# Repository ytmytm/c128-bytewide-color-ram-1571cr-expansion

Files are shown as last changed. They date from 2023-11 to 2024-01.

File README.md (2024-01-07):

# C128 8-bit Color RAM and C128DCR 1571CR RAM expansion

This is a 24 to 28 pin adapter PCB that can be used for three different C128 modifications:

- widen 2K Color RAM to 8 bits (C128/C128D/C128DCR)
- widen Color RAM to 8 bits and expand to 32K (C128/C128D/C128DCR)
- RAM Expansion for 1571CR compatible with Maverick (C128DCR only)

## Schematic

PDF plot of [the schematic can be found here](kicad/plots/kicad-c128-byte-wide-color-ram.pdf).

[kicad](kicad/) folder contains all the KiCad 6.0 project files.

## PCB

[kicad/plots](kicad/plots) folder contains Gerber files for manufacturing a PCB for any of these projects.

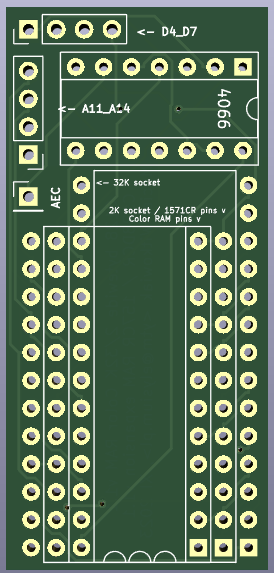
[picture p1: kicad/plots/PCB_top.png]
Top side of the PCB
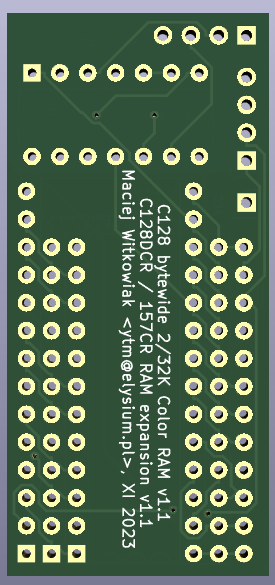
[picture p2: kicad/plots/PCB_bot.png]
Bottom side of the PCB


# 8-bit Color RAM

## Background

The idea comes from [a project published in 1990](http://www.sdiy.org/richardc64/color/byte.html).

All C128 variations use 8x2K SRAM chip (2016) for Color RAM. Although RAM is 8-bit, only lower 4 bits are connected. Lines D4-D7 are pulled up by a resistor pack to 5V.
This project replicates part of the onboard circuit and adds a quad switch 4066 as a bidirectional buffer between higher 4 bits and CPU bus.
Like the onboard U20 (4066) it switches Color RAM on/off bus, depending on the state of AEC line.

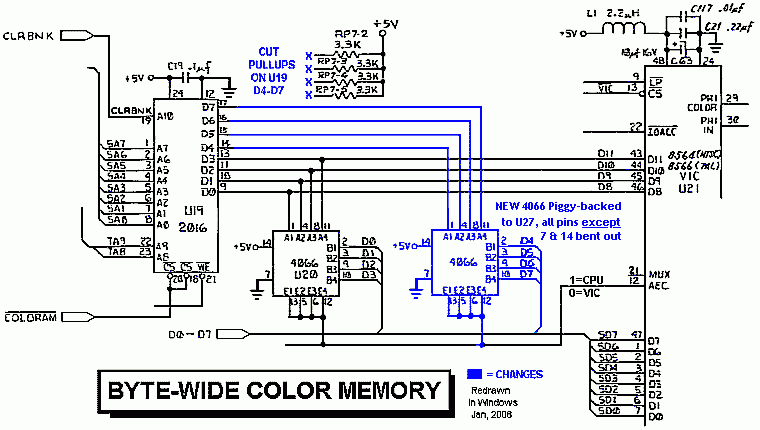
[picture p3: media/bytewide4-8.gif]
Schematic from http://www.sdiy.org/richardc64/color/byte.html


Note: this schematic shows the general idea. Don't cut anything on the mainboard and don't piggyback chips

## Why?

For sure it doesn't add any colors. However having 1K (2K in C128 mode) of additional RAM may be useful for some projects. It is compatible with any other expansion or cartidge.

## 32K option

Even more of that RAM? Possibilities are endless, but how to switch the banks?

VIC utilizes 1K of Color RAM, but C128 was equipped with double of that amount to support split screen multicolor graphics in BASIC. The bank switching between lower 1K and upper 1K is done using CPU port at location $01.
In C64 mode this port decides about RAM/ROM configuration, in C128 mode lower two bits determine which half of 2K Color RAM is seen by VIC and which half by CPU.

It only made sense to me to extend this further and use other $01 port bits to provide more address lines for 32K Color RAM expansion. None of my C128s will be ever used with tape (or even TapeCart), so I connected A11-13 lines to
lines normally used by tape motor control, tape write and sense bits. This provides 13 bits of address, so 16K total.

You don't need to connect all of them or you can skip it altogether. I have reused connections to onboard pull-up resistors to pull these address lines high if nothing is connecte to the solder pads.

Until I have a better idea where to connect A14 I will be happy with using 16K of that RAM. That's enough for 16 full screens: 8 for imaginary FLI mode with color ram switched every line and another 8 for interlaced option.

Note that a lot of C64 software will write to CPU port ($01) location and can modify the status of tape control bits. If you're not planning to use tape device I highly recommend patching the ROM (details below)
to set these bits as input by default. This completely removes the problem as virtually no software modifies CPU port direction register ($00).

## Assembly

Parts needed:

- 24-pin socket to be soldered in place of removed U19
- two sets of 12 round pins (24 total)
- 4066 analog quad switch and 14-pin socket for it
- 24-pin socket for 2K SRAM (2016) *or* 28-pin socket for 32K SRAM (62256)
- 8x2K RAM (ideally 2016 desoldered from the board) *or* 8x32K SRAM (62256)

In any case you need to remove or desolder the original 2K chip (U19) and replace it by a 24-pin socket. PCB is meant to be equipped with round pins and plugged into that socket.
We also need some signals from the board, so additional wires will be needed.

Start assembly by soldering in two rows of 24 round pins that will be used to plug in PCB to the C128/D/DCR mainboard.
For this project you need to solder them in the row of holes closest to the PCB edge and the one marked on silkscreen, on the image below marked by RED.

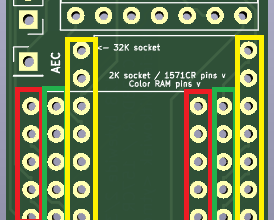
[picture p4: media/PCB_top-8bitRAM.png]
colour-coded pins


For 2K option solder the 24-pin socket in holes marked GREEN. For 32K option solder 28-pin socket in holes marked YELLOW.

The last step of the assembly is soldering in 14-pin socket for 4066.

## Installation

Once the assembled PCB is plugged into place of original SRAM (U19) (*mind the orientation*) you need to connect five additional wires to the mainboard:

- connect AEC from onboard U20 (4066) any pin 5, 6, 12 or 13 - they are all connected together
- connect D4-D7 in any order from charset ROM nearby or from convenient vias. You may have 24 or 28-pin ROM there, so check the pinout and verify against e.g. CPU

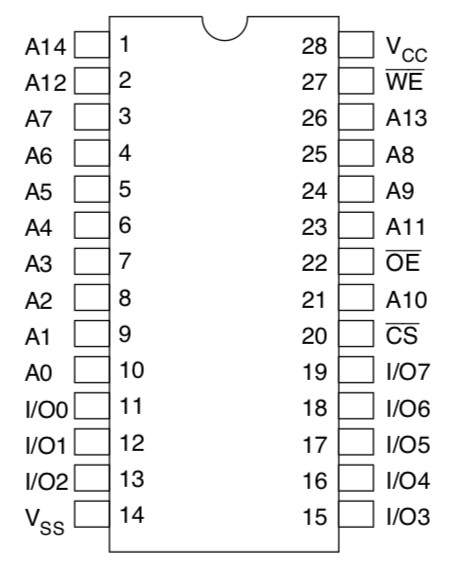
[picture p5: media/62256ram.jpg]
62256 SRAM pinout


D4-D7 lines are on the right bottom end of the chip.

**Note:** if you don't have 2K SRAM chip or it was damaged during desoldering you can just pop in 32K SRAM chip (still available these days) and stop here.
If you look on the schematics I have routed onboard D4-D7 lines (pulled high by onboard resistors) to A11-A14 lines.
So if you don't connect there anything at all they will be driven high and even with 32K SRAM those 2K of Color RAM will be available with no extra connections.

## Installation (32K Color RAM)

- connect A11/A12/A13 to CPU tape ports P3/P4/P5 from CPU socket (pins 27/26/25) or from convenient vias

Like with data lines it doesn't really matter in which order you connect those tape motor/write/sense connections to solder points A11-A14 lines or even if you leave A11 or A14 unconnected.

I wanted to avoid soldering directly to CPU (or underneath CPU) even though I have it already socketed. Instead I found several vias for convenient access.

For C128/C128D I found it invaluable to open [C128 Neo project in KiCad](https://github.com/jgrip/open128) and highlight ports and their net (using `` key) to see where they cross the board sides.

Here is how it can look like on C128D. It's already a mess off wires on that machine but you get the general idea:

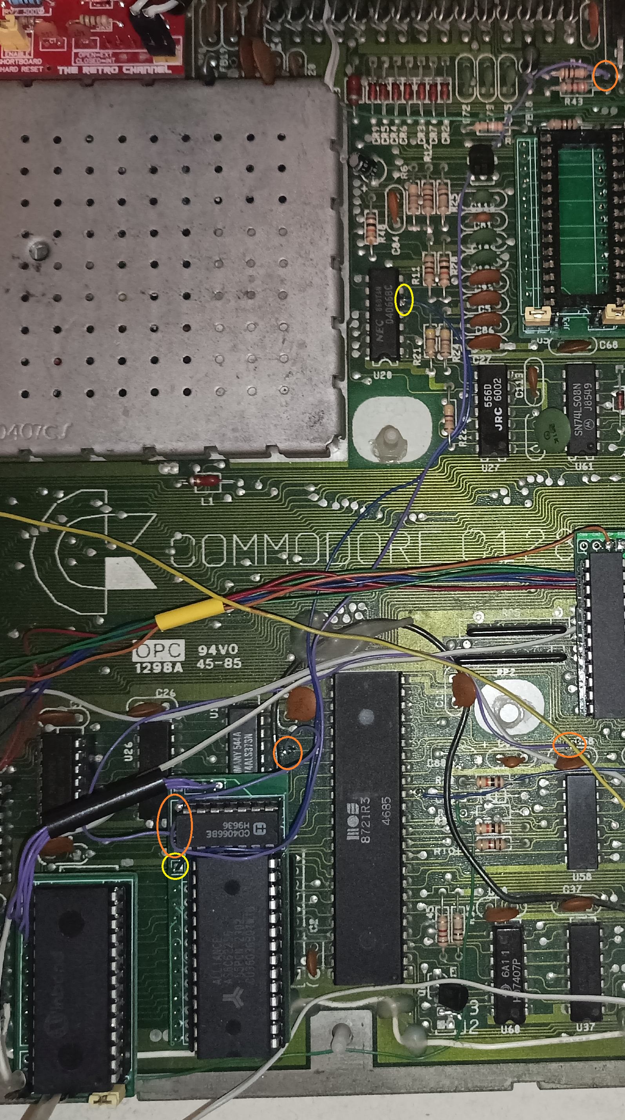
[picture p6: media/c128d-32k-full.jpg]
32K Color RAM connection on C128D


- YELLOW points show AEC connection to U20
- ORANGE points show A11/A12/A13 connections to two vias and one side of R4 resistor
- A14 is not connected to anything
- data lines D4-D7 are connected to character ROM adapter nearby

## Testing

In C128 mode in monitor try:

```
M FD800 FD8080
```

then edit some values and try issuing the command again. You should see that the top four bits (first hex digit) hold their value.

## Testing (32K Color RAM)

Extra address lines are controlled by CPU port. First let's switch them all to output (as tape sense is an input by default):

```
POKE 0, PEEK(0) OR (8+16+32)
```

Then try to put some colored text on screen and switch RAM banks back and forth by using various combinations of bits 3, 4 and 5

```
X = PEEK(1) AND 199
POKE 1, X
POKE 1, X OR 8
POKE 1, X OR (8+16)
POKE 1, X OR 32
...
```

## Patching ROM (32K Color RAM)

C64/128 ROM will set the CPU port direction register ($00) to value $2F. This sets up bits 5 and 3 as outputs because they control tape motor and tape write lines. However a lot of C64 software will write to CPU port ($01)
and modify bits 3/4/5 that we allocated to select Color RAM banks. This doesn't break anything but may cause flicker or random screen colors during some operations (e.g. decompressing) - as if Color RAM was faulty.

An easy way to fix this is to patch Kernal C64 and C128 to set $00 to make all bits 3/4/5 as inputs by default. This can be easy accomplished with a hex editor such as [HxD](https://mh-nexus.de/en/hxd/).

For a 32K ROM for C128DCR (U32), or C128D modified to use 32K chips, use this already patched file: [U32.complete.318023-02-patched.bin](rom/U32.complete.318023-02-patched.bin).

1. Dump from onboard chips (or download from [zimmers.net](http://www.zimmers.net/anonftp/pub/cbm/firmware/computers/c128/index.html) ROM appropriate to your C128: 16K for unmodified C128D or 32K for C128DCR

2. Use hex editor to patch the ROM - search for values `A9 2F 85 00` and replace `2F` by `07`. In American ROM (complete.318023-02.bin) that value appears at offsets:

- `$3DDA` - C64 Kernal soft reset (real address `$FDDA`)
- `$613D` - C128 Kernal soft reset (real address `$FE13D`)
- `$6250` - C128 Kernal GO64 (real address `$FE250`)

3. If you have JiffyDOS or a 64K ROM with a switch that value will appear three more times in the second 32K half of the ROM. Patch it as well from `2F` to `07`.

4. Save and flash into a new EEPROM to replace onboard ROM U32 (DCR)

## Patching VICE (32K Color RAM)

If you can recompile [VICE](https://vice-emu.sourceforge.io/) on your own, here is a patch to enable 32K Color RAM emulation.

[ytm-c128-colorram-expansion.patch](vice/ytm-c128-colorram-expansion.patch)

This is based off VICE 3.8 release (28 December 2023, revision 44935).

You will find new option in `Settings -> Machine -> Mode -> Miscellaneous -> Expand color RAM...`.

This can be passed also from command line via `-c128colorramexpansion` option.

# 1571CR RAM expansion

## Background

Since I already had this PCB, which also does 2K (24 pin) to 32K (28 pin) conversion I had a closer look on the second 2016 2K SRAM chip present on C128DCR board.

This is 1571 RAM. In standard configuration there are exactly 2K of SRAM in range $0000-$07FF, just like on 1541.

There are [several projects that expand RAM on external 1571 and 1541s](http://d81.de/CLD-RAMBOard/References.shtml), but I couldn't find anything for 1571CR (internal 1571 of C128DCR).

I found a [memory map on zimmers.net](http://www.zimmers.net/anonftp/pub/cbm/schematics/drives/new/1571/memorymap.txt)
that described $6000-$7FFF range as "RAM shadows", so I conducted an experiment.

I have removed U103 (2016 2K SRAM) and put in this place a 24 to 28 pin adapter for 62256 (32K SRAM) and I connected A11-A14 directly to U101 (6502 CPU).
It worked right away with no extra parts. I was able to copy disks with Maverick v5 RAMBoard nibbler.

After more testing I saw that RAM is actualy present also in $0800-$0FFF range. In both $0000-$0FFF and $6000-$7FFF ranges that provides a total of 12K available.

## Why?

The only purpose seems to be [Maverick v5 RAMBoard nibbler](https://csdb.dk/release/?id=18107). [DolphinDOS uses extra memory](https://e4aws.silverdr.com/projects/dolphindos3/) but there is no way to add a parallel port to 1571CR in a way DolphinDOS expects - all these VIA port lines are
already used.

In Maverick to go 'GCR Nibbler' option and choose 'RAMBoard'. In further settings choose $6000-$7FFF area for RAM.

## Assembly

Parts needed:

- 24-pin socket to be soldered in place of removed U103
- two sets of 12 round pins (24 total)
- 28-pin socket for 32K SRAM (62256)
- 8x32K SRAM (62256)

You need to remove or desolder the original 2K chip (U103) and replace it by a 24-pin socket. PCB is meant to be equipped with round pins and plugged into that socket.
We also need some signals from the board, so additional wires will be needed.

Start assembly by soldering in two rows of 24 round pins that will be used to plug in PCB to the C128DCR mainboard.

For this project you need to leave RED holes unoccupied and solder round pins in the middle row of holes from the PCB edge, on the image below marked by GREEN.

colour-coded pins

Solder 28-pin socket in holes marked YELLOW. You don't need to do anything about 14-pin 4066 either, that won't be used.

Here is how it looks like. Don't mind the orange and yellow wires. These are jumpers that I missed to route in the first version of the board. Current project has it already fixed.

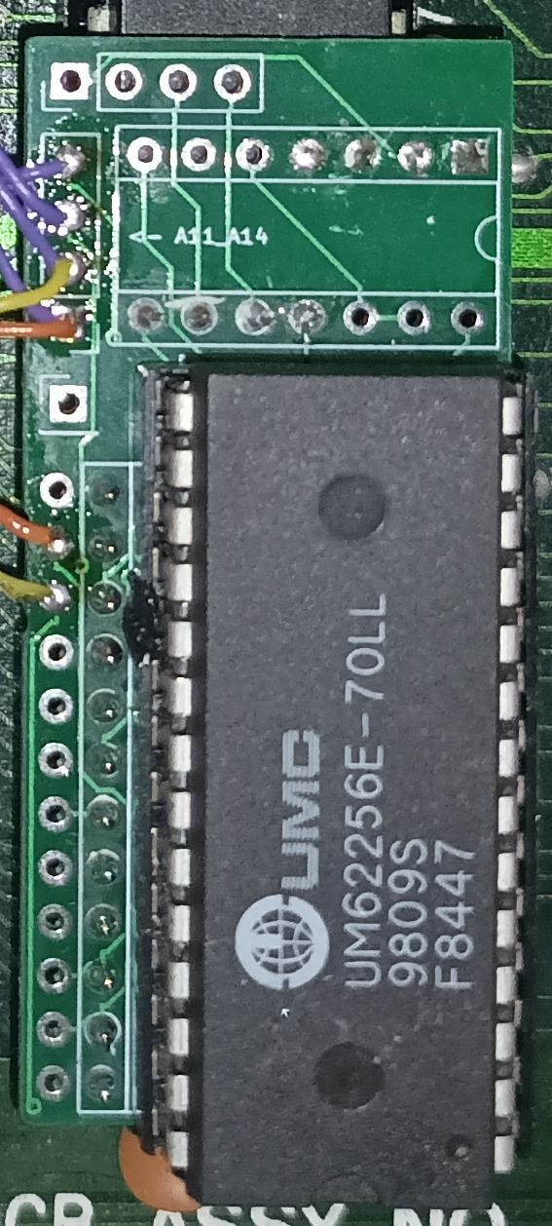
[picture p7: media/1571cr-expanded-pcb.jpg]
1571CR daughterboard closeup


## Installation

Once the assembled PCB is plugged into place of original SRAM (U103) (*mind the orientation*) you need to connect four additional wires to the mainboard: the new address lines.

In the prototype I soldered them directly to the CPU (U101) pins 20, 22, 23 and 24, but I don't like this solution in the long run:

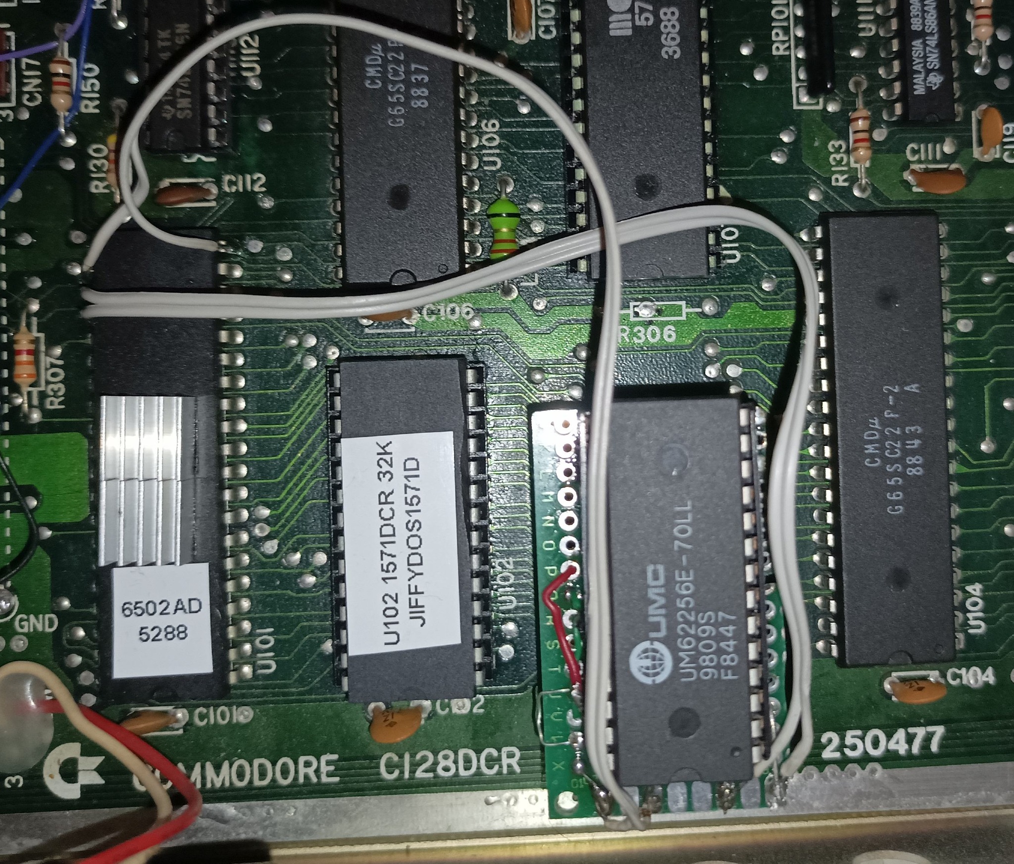
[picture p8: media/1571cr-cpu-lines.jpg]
1571CR daughterboard with address lines connected to CPU


There are four vias where these address lines can be found:

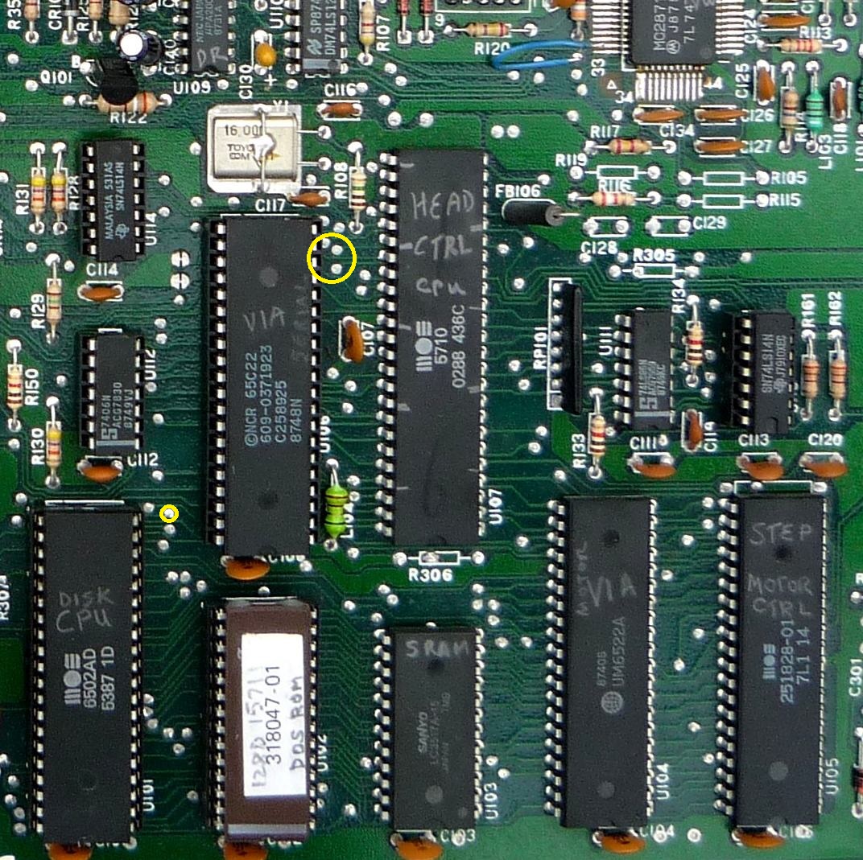
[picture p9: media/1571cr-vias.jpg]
C128DCR with A11-A14 vias marked


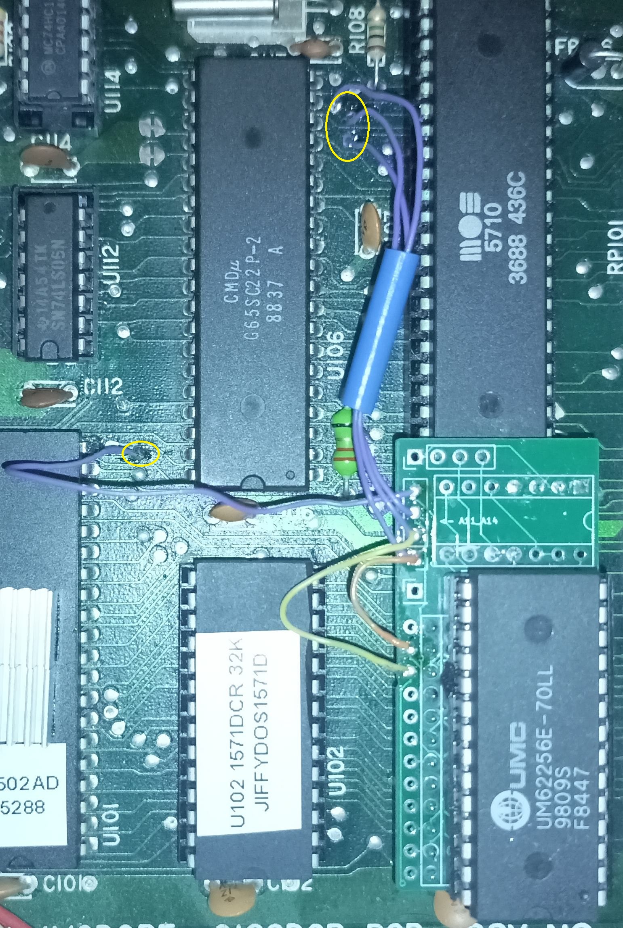
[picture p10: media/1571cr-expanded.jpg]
C128DCR with A11-A14 vias connected and marked


## Testing

You can use test program from [RAMBOard test/demo disk](media/ramboard.zip) (cached from http://d81.de/CLD-RAMBOard/refs/ramboard.zip). For whatever reason the test program works but disk copier doesn't.

If you have JiffyDOS, it's easy to use JiffyMon in C64 mode. It can be [downloaded from CSDB](https://csdb.dk/release/?id=16906) with [PDF manual available here](http://slark.me/c64-downloads/jiffymon-machine-language-monitor-users-guide.pdf)

Commands with asterisk will act on the default drive memory, like:
```
M* 6000 6080
```
or copy data between C128 and the drive - from range $6000-$6080 to $0400 (top of screen):
```
MR 6000 6080 0400
```
and back from computer to the drive:
```
MW 0400 0480 6000
```

Restart monitor with
```
SYS 64715
```

For actual disk copying get Maverick V5 and after choosing GCR Nibbler select RAMBOard option. Then set it up for RAM that starts at $6000.

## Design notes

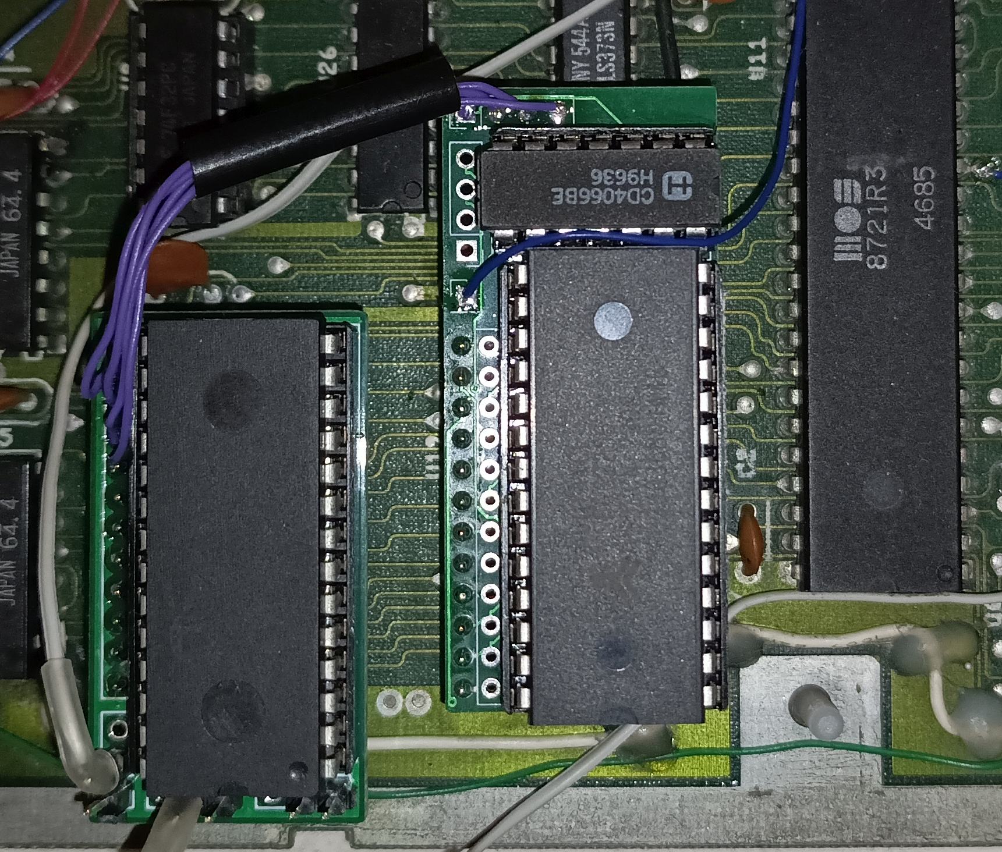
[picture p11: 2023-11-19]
media/c128d-32k-no-a11-a14.jpg

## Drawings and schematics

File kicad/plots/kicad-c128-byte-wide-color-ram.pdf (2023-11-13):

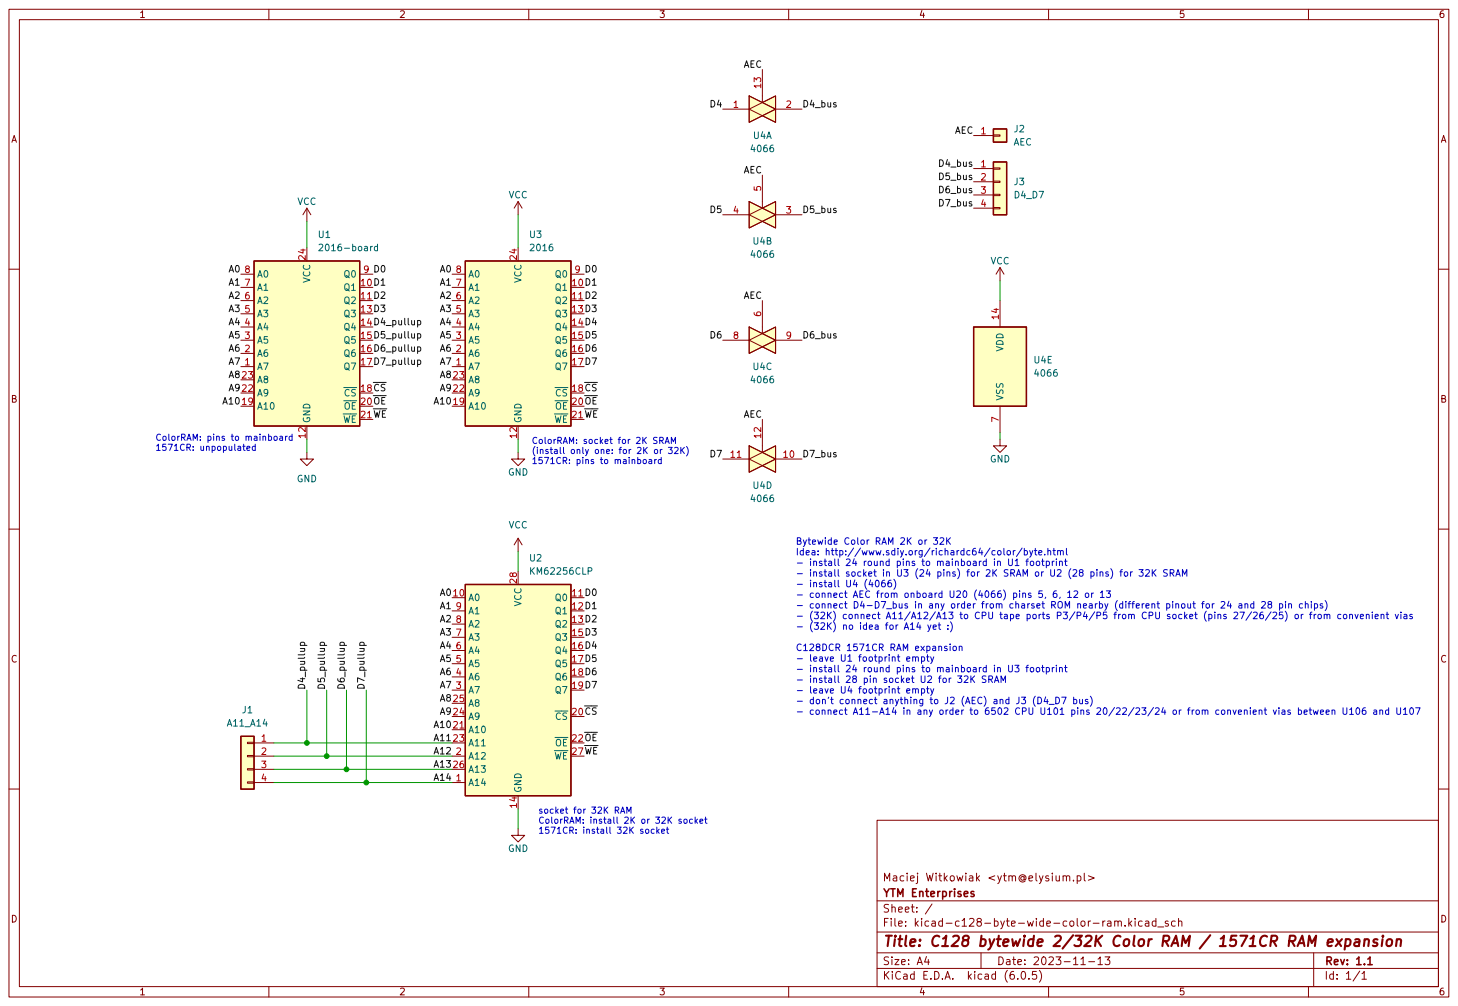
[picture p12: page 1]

(install only one: for 2K or 32K) 1571CR: pins to mainboard ColorRAM: pins to mainboard
1571CR: unpopulated

ColorRAM: socket for 2K SRAM

Idea: http://www.sdiy.org/richardc64/color/byte.html
- install 24 round pins to mainboard in U1 footprint
- install socket in U3 (24 pins) for 2K SRAM or U2 (28 pins) for 32K SRAM
- install U4 (4066)
- connect AEC from onboard U20 (4066) pins 5, 6, 12 or 13
- connect D4-D7_bus in any order from charset ROM nearby (different pinout for 24 and 28 pin chips)
- (32K) connect A11/A12/A13 to CPU tape ports P3/P4/P5 from CPU socket (pins 27/26/25) or from convenient vias
- (32K) no idea for A14 yet :)

C128DCR 1571CR RAM expansion
- leave U1 footprint empty
- install 24 round pins to mainboard in U3 footprint
- install 28 pin socket U2 for 32K SRAM
- leave U4 footprint empty
- don't connect anything to J2 (AEC) and J3 (D4_D7 bus)
- connect A11-A14 in any order to 6502 CPU U101 pins 20/22/23/24 or from convenient vias between U106 and U107

Maciej Witkowiak <ytm@elysium.pl>
File: kicad-c128-byte-wide-color-ram.kicad_sch Sheet: / YTM Enterprises

Id: 1/1 Title: C128 bytewide 2/32K Color RAM / 1571CR RAM expansion

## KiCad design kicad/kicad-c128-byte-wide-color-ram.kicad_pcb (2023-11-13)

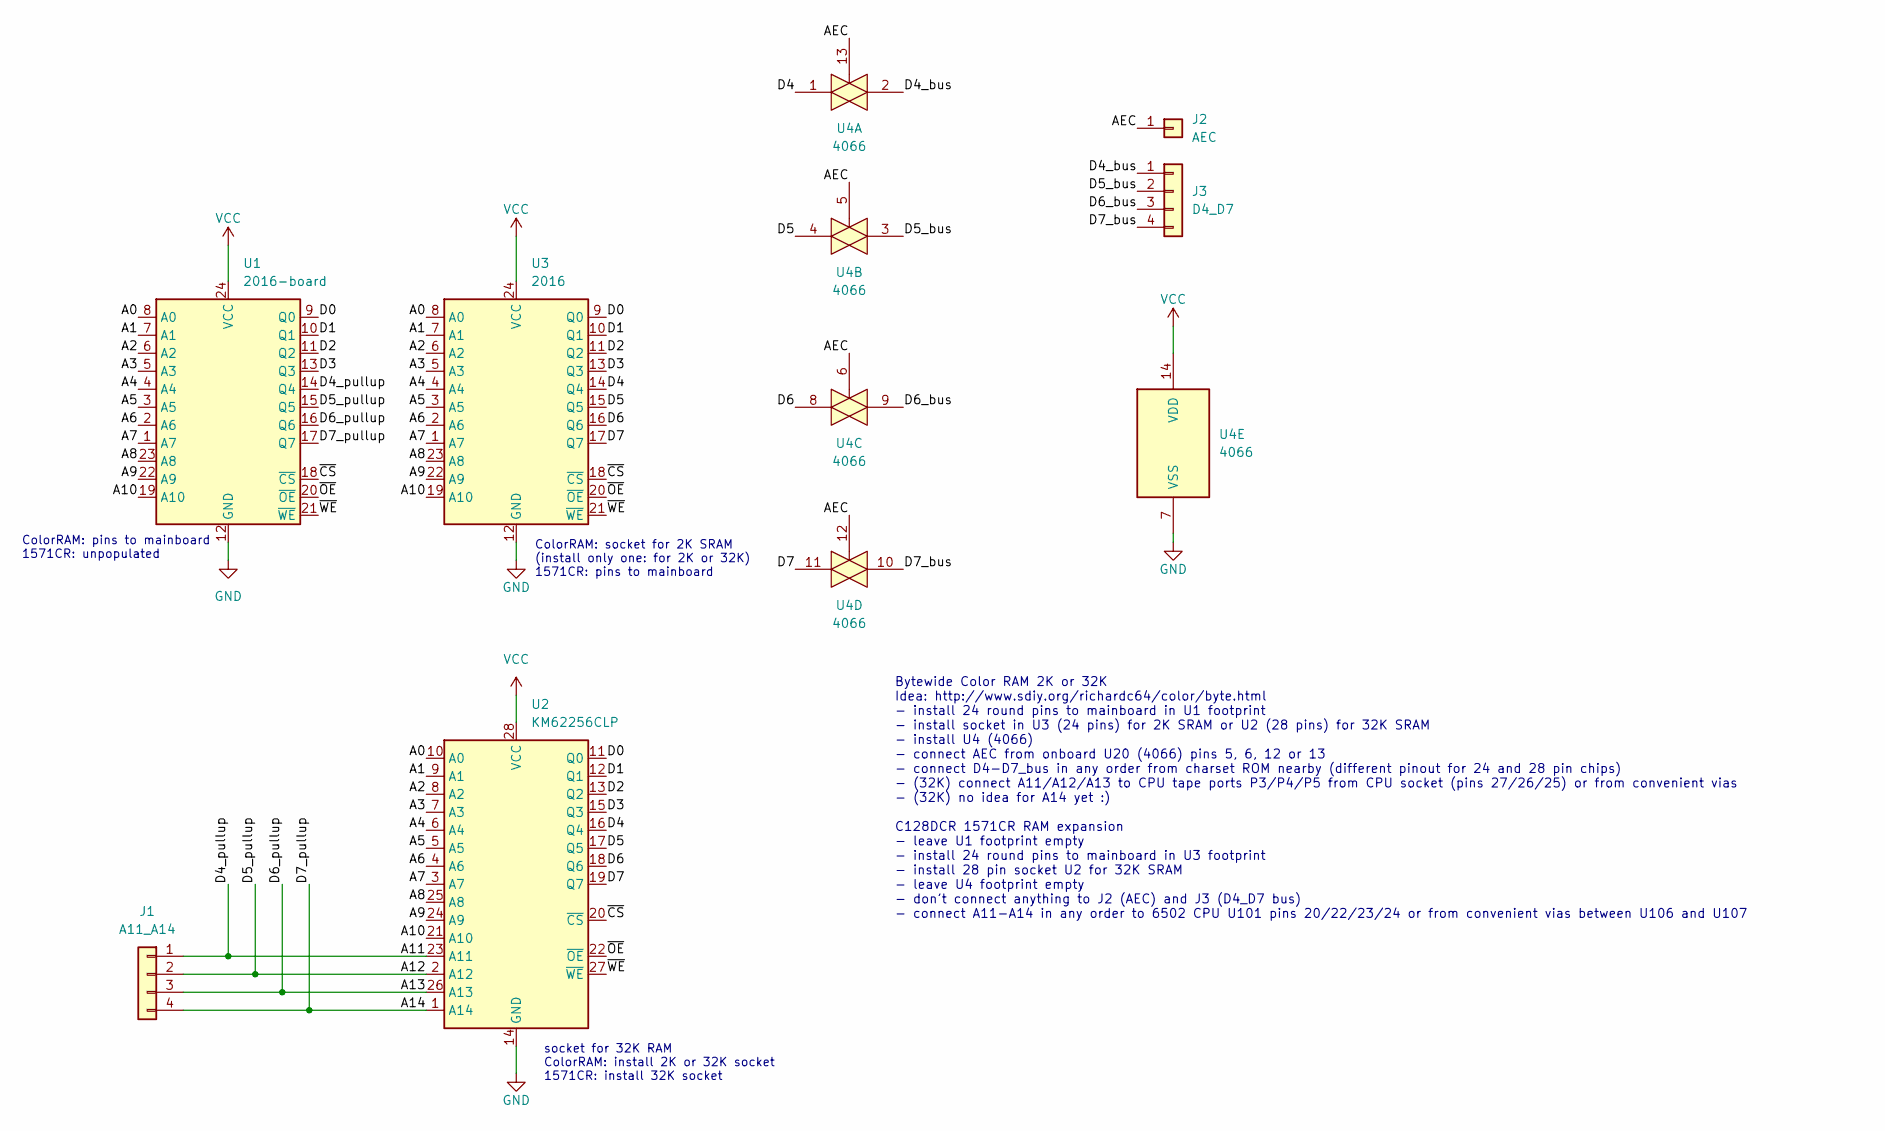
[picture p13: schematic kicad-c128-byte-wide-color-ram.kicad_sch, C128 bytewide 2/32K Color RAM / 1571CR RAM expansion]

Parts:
J1: A11_A14; PinHeader_1x04_P2.54mm_Vertical
J2: AEC; PinHeader_1x01_P2.54mm_Vertical
J3: D4_D7; PinHeader_1x04_P2.54mm_Vertical
U1: 2016-board; DIP-24_W15.24mm
U2: KM62256CLP; DIP-28_W15.24mm
U3: 2016; DIP-24_W15.24mm
U4: 4066; DIP-14_W7.62mm_Socket

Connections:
/A0: U1.8 (A0), U2.10 (A0), U3.8 (A0)
/A1: U1.7 (A1), U2.9 (A1), U3.7 (A1)
/A2: U1.6 (A2), U2.8 (A2), U3.6 (A2)
/A3: U1.5 (A3), U2.7 (A3), U3.5 (A3)
/A4: U1.4 (A4), U2.6 (A4), U3.4 (A4)
/A5: U1.3 (A5), U2.5 (A5), U3.3 (A5)
/A6: U1.2 (A6), U2.4 (A6), U3.2 (A6)
/A7: U1.1 (A7), U2.3 (A7), U3.1 (A7)
/A8: U1.23 (A8), U2.25 (A8), U3.23 (A8)
/A9: U1.22 (A9), U2.24 (A9), U3.22 (A9)
/A10: U1.19 (A10), U2.21 (A10), U3.19 (A10)
/A11: J1.1, U1.14 (Q4), U2.23 (A11)
/A12: J1.2, U1.15 (Q5), U2.2 (A12)
/A13: J1.3, U1.16 (Q6), U2.26 (A13)
/A14: J1.4, U1.17 (Q7), U2.1 (A14)
/AEC: J2.1, U4.5, U4.6, U4.12, U4.13
/D0: U1.9 (Q0), U2.11 (Q0), U3.9 (Q0)
/D1: U1.10 (Q1), U2.12 (Q1), U3.10 (Q1)
/D2: U1.11 (Q2), U2.13 (Q2), U3.11 (Q2)
/D3: U1.13 (Q3), U2.15 (Q3), U3.13 (Q3)
/D4: U2.16 (Q4), U3.14 (Q4), U4.1
/D4_bus: J3.1, U4.2
/D5: U2.17 (Q5), U3.15 (Q5), U4.4
/D5_bus: J3.2, U4.3
/D6: U2.18 (Q6), U3.16 (Q6), U4.8
/D6_bus: J3.3, U4.9
/D7: U2.19 (Q7), U3.17 (Q7), U4.11
/D7_bus: J3.4, U4.10
/~CS: U1.18 (~CS), U2.20 (~CS), U3.18 (~CS)
/~OE: U1.20 (~OE), U2.22 (~OE), U3.20 (~OE)
/~WE: U1.21 (~WE), U2.27 (~WE), U3.21 (~WE)
GND: U1.12 (GND), U2.14 (GND), U3.12 (GND), U4.7 (VSS)
VCC: U1.24 (VCC), U2.28 (VCC), U3.24 (VCC), U4.14 (VDD)

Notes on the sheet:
Bytewide Color RAM 2K or 32K Idea: http://www.sdiy.org/richardc64/color/byte.html - install 24 round pins to mainboard in U1 footprint - install socket in U3 (24 pins) for 2K SRAM or U2 (28 pins) for 32K SRAM - install U4 (4066) - connect AEC from onboard U20 (4066) pins 5, 6, 12 or 13 - connect D4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
ColorRAM: socket for 2K SRAM (install only one: for 2K or 32K) 1571CR: pins to mainboard
socket for 32K RAM ColorRAM: install 2K or 32K socket 1571CR: install 32K socket
ColorRAM: pins to mainboard 1571CR: unpopulated

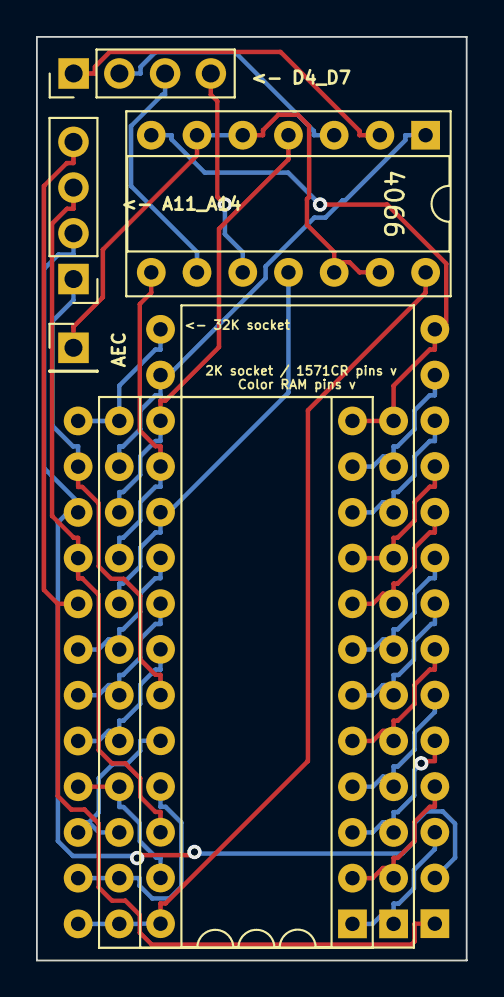
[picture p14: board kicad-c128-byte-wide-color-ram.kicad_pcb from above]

Board: 2 copper layers, 23.9 x 51.3 mm, 7 parts (0 on the bottom side), 33 nets.

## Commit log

2023-10-24 initial commit, board printout fit tested to both c128d and c128dcr
    [kicad-c128-byte-wide-color-ram-B_Cu.gbl, kicad-c128-byte-wide-color-ram-B_Mask.gbs, kicad-c128-byte-wide-color-ram-B_Paste.gbp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]
2023-10-24 directory rename
    [kicad-c128-byte-wide-color-ram-B_Cu.gbl, kicad-c128-byte-wide-color-ram-B_Mask.gbs, kicad-c128-byte-wide-color-ram-B_Paste.gbp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]
2023-11-13 revision 1.1 with 1571CR info
    [kicad-c128-byte-wide-color-ram-B_Cu.gbl, kicad-c128-byte-wide-color-ram-B_Mask.gbs, kicad-c128-byte-wide-color-ram-B_Paste.gbp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]
